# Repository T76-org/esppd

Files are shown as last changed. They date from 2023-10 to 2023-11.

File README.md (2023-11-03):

# ESPPD: a ESP32-S3 board with built-in USB-C PD controller

ESPPD

ESPPD is an ESP32-S3 breakout board that incorporates the ability to interface with a USB-C PD-compatible power supply to request a specific voltage. It features:

- **Hacker-friendly design**
  - Plug-and-play compatibility with Arduino and PlatformIO
  - Fits a standard breadboard, leaving a row of pins on each side for easy connectivity
  - Most ESP32-S3 pins available at the headers
  - 3.3V, VBUS (USB-PD input voltage), and GND pins on both sides
- **ESP32-S3-WROOM-1 module**
  - Dual 240 MHz dual-core Tensilica LX7 CPU
  - 2.4 GHz Wi-Fi (802.11n) and Bluetooth 5.0
  - 8MB SPI flash
  - 384 KB SRAM
- **USB-C PD 2.0 compatible controller**
  - Ability to request 5V, 9V, 12V, 15V, or 20V from a compatible supply
  - Ability to request a fixed voltage using hardwired jumpers, or dynamically via code
  - Ability to detect whether the requested voltage has actually been supplied (power-good signal)
- **Separate USB-C connectors for power and data**
  - Direct programming via USB; no UART required
  - USB 2.0 data connection
  - Support for USB host and client configuration
  - Serial I/O via USB supported out of the box
- **Indicators**
  - Power LED (red)
  - Software-controllable blue LED

## Hardware

The ESPPD incorporates a [CH224K](https://www.wch-ic.com/downloads/file/302.html) USB-PD controller that handles the negotiation with a PD-compatible power supply to request a specific voltage. The CH224K is configured to request 5V by default, but [can be configured](https://github.com/T76-org/esppd/wiki/Interfacing-with-USB-PD-devices) to request 5V, 9V, 12V, 15V, or 20V using either hardwired jumpers or dynamically via firmware. The CH224K also monitors the voltage supplied by the power supply and can report whether the requested voltage has actually been supplied, thus allowing your code to only operate under the correct conditions.

## ESP32-S3 compatibility

The board is compatible with the [ESP32-S3-WROOM-1](https://www.espressif.com/sites/default/files/documentation/esp32-s3-wroom-1_wroom-1u_datasheet_en.pdf) module from Espressif. The module features a dual-core 240 MHz Tensilica LX7 CPU, 4MB of SPI flash, up to 8MB of PSRAM, and 384 KB of SRAM. The module also features 2.4 GHz Wi-Fi (802.11n) and Bluetooth 5.0.

## Pinout

Pinout

For additional information on the features associated with each pin, you can consult [Espressif's ESP32-S3 datasheet](https://www.espressif.com/sites/default/files/documentation/esp32-s3_datasheet_en.pdf).

## Further reading

For more information on how to build and upload your code to the board, interact with a USB-PD power supply, and troubleshoot any problems, see the [wiki](https://github.com/T76-org/esppd/wiki).

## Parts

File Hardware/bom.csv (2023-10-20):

Designator | Footprint | Quantity | Value | LCSC Part #
C1, C5, C6 | 0402 | 3 | 1µ | C52923
C2, C3 | 1206 | 2 | 10µ | C13585
C4 | 0603 | 1 | 100n | C14663
C7 | 0603 | 1 | 22µ | C59461
C8 | 0402 | 1 | 100n | C1525
D1 | SMA_L4.3-W2.6-LS5.2-RD | 1 | SS34 | C8678
D2 | 0603 | 1 | POWER | C2286
D3 | 0603 | 1 | LED | C72041
J1 | PinHeader_1x22_P2.54mm_Vertical | 1 | Left
J2 | PinHeader_1x22_P2.54mm_Vertical | 1 | Right
JP1, JP2, JP3 | SolderJumper-3_P1.3mm_Open_RoundedPad1.0x1.5mm_NumberLabels | 3 | Jumper_3_Open
JP4 | SolderJumper-2_P1.3mm_Open_RoundedPad1.0x1.5mm | 1 | Jumper_2_Open
L1 | IND-SMD_L4.5-W4.0 | 1 | PSPCAQ43-100M | C436403
R1, R10, R11, R5, R6, R9 | 0402 | 6 | 10k | C25744
R12 | 0402 | 1 | 300R | C25102
R2, R7, R8 | 0402 | 3 | 1k | C11702
R3 | 0603 | 1 | 13k | C22797
R4 | 0603 | 1 | 3k9 | C23018
SW1, SW2 | SW-SMD_4P-L5.1-W5.1-P3.70-LS6.5-TL-2 | 2 | RESET | C318884
U2 | ESP32-S3-WROOM-1 | 1 | ESP32-S3-WROOM-1
U3 | SOT-23-6_L2.9-W1.7-P0.95-LS2.8-BL | 1 | LGS5145 | C5123971
U4 | ESSOP-10_L4.9-W3.9-P1.0-LS6.0-TL-EP | 1 | CH224K | C970725
USB1 | USB-C_SMD-TYPE-C-31-M-12 | 1 | PWR | C2927038
USB2 | USB-C_SMD-TYPE-C-31-M-12 | 1 | DATA | C2927038

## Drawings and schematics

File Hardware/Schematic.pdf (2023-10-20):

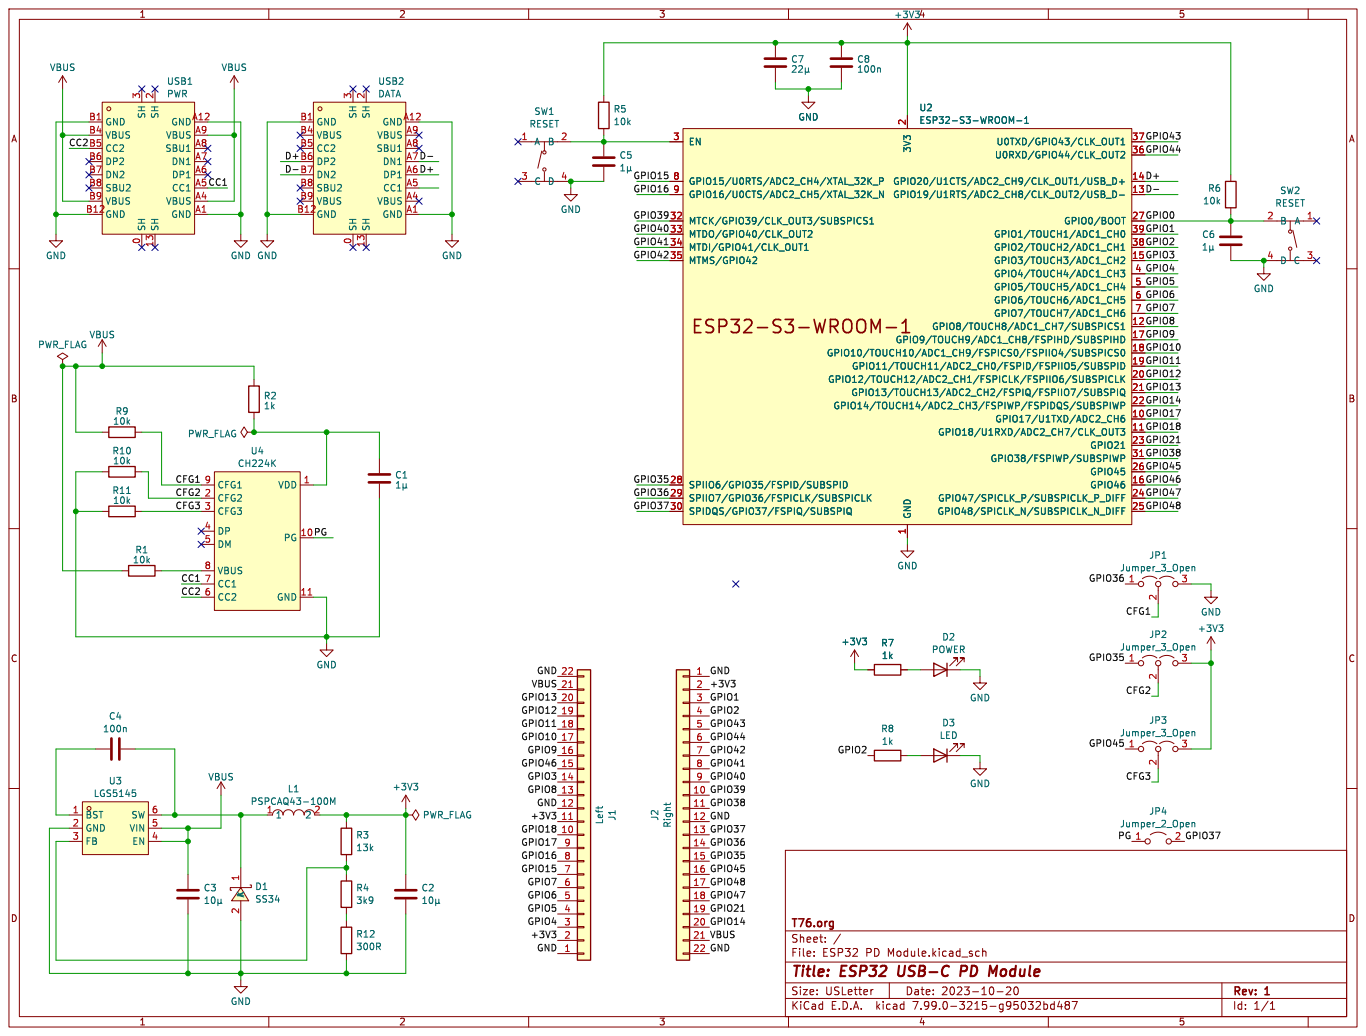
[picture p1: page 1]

3 GND A1 GNDA12 VBUS A4 CC1 A5 DP1 A6 DN1 A7 SBU1 A8 VBUS A9 GND B1 GND B12 VBUS B4 CC2 B5 DP2 B6 DN2 B7 SBU2 B8 VBUS B9 USB1 PWR GND

3 GND A1 GNDA12 VBUS A4 CC1 A5 DP1 A6 DN1 A7 SBU1 A8 VBUS A9 GND B1 GND B12 VBUS B4 CC2 B5 DP2 B6 DN2 B7 SBU2 B8 VBUS B9 USB2 DATA R5

2 GPIO12/TOUCH12/ADC2_CH1/FSPICLK/FSPIIO6/SUBSPICLK 20 GPIO13/TOUCH13/ADC2_CH2/FSPIQ/FSPIIO7/SUBSPIQ 21 GPIO14/TOUCH14/ADC2_CH3/FSPIWP/FSPIDQS/SUBSPIWP 22 GPIO21 23 GPIO47/SPICLK_P/SUBSPICLK_P_DIFF 24 GPIO48/SPICLK_N/SUBSPICLK_N_DIFF 25 GPIO45 26 GPIO0/BOOT 27 SPIIO6/GPIO35/FSPID/SUBSPID 28 SPIIO7/GPIO36/FSPICLK/SUBSPICLK 29 EN 3 SPIDQS/GPIO37/FSPIQ/SUBSPIQ 30 GPIO38/FSPIWP/SUBSPIWP 31 MTCK/GPIO39/CLK_OUT3/SUBSPICS1 32 MTDO/GPIO40/CLK_OUT2 33 MTDI/GPIO41/CLK_OUT1 34 MTMS/GPIO42 35 U0RXD/GPIO44/CLK_OUT2 36 U0TXD/GPIO43/CLK_OUT1 37 GPIO2/TOUCH2/ADC1_CH1 38 GPIO1/TOUCH1/ADC1_CH0 39 GPIO4/TOUCH4/ADC1_CH3 4 GPIO5/TOUCH5/ADC1_CH4 5 GPIO6/TOUCH6/ADC1_CH5 6 GPIO7/TOUCH7/ADC1_CH6 7 GPIO15/U0RTS/ADC2_CH4/XTAL_32K_P 8 GPIO16/U0CTS/ADC2_CH5/XTAL_32K_N 9 U2ESP32-S3-WROOM-1 SH

2 GPIO12/TOUCH12/ADC2_CH1/FSPICLK/FSPIIO6/SUBSPICLK 20 GPIO13/TOUCH13/ADC2_CH2/FSPIQ/FSPIIO7/SUBSPIQ 21 GPIO14/TOUCH14/ADC2_CH3/FSPIWP/FSPIDQS/SUBSPIWP 22 GPIO21 23 GPIO47/SPICLK_P/SUBSPICLK_P_DIFF 24 GPIO48/SPICLK_N/SUBSPICLK_N_DIFF 25 GPIO45 26 GPIO0/BOOT 27 SPIIO6/GPIO35/FSPID/SUBSPID 28 SPIIO7/GPIO36/FSPICLK/SUBSPICLK 29 EN 3 SPIDQS/GPIO37/FSPIQ/SUBSPIQ 30 GPIO38/FSPIWP/SUBSPIWP 31 MTCK/GPIO39/CLK_OUT3/SUBSPICS1 32 MTDO/GPIO40/CLK_OUT2 33 MTDI/GPIO41/CLK_OUT1 34 MTMS/GPIO42 35 U0RXD/GPIO44/CLK_OUT2 36 U0TXD/GPIO43/CLK_OUT1 37 GPIO2/TOUCH2/ADC1_CH1 38 GPIO1/TOUCH1/ADC1_CH0 39 GPIO4/TOUCH4/ADC1_CH3 4 GPIO5/TOUCH5/ADC1_CH4 5 GPIO6/TOUCH6/ADC1_CH5 6 GPIO7/TOUCH7/ADC1_CH6 7 GPIO15/U0RTS/ADC2_CH4/XTAL_32K_P 8 GPIO16/U0CTS/ADC2_CH5/XTAL_32K_N 9 R7

1 GPIO17/U1TXD/ADC2_CH6 10 GPIO18/U1RXD/ADC2_CH7/CLK_OUT3 11 GPIO8/TOUCH8/ADC1_CH7/SUBSPICS1 12 GPIO19/U1RTS/ADC2_CH8/CLK_OUT2/USB_D- 13 GPIO20/U1CTS/ADC2_CH9/CLK_OUT1/USB_D+ 14 GPIO3/TOUCH3/ADC1_CH2 15 GPIO46 16 GPIO9/TOUCH9/ADC1_CH8/FSPIHD/SUBSPIHD 17 GPIO10/TOUCH10/ADC1_CH9/FSPICS0/FSPIIO4/SUBSPICS0 18 GPIO11/TOUCH11/ADC2_CH0/FSPID/FSPIIO5/SUBSPID 19 3V3

Id: 1/1 Title: ESP32 USB-C PD Module

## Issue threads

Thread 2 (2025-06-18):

Testing with Apple charger

sumit809, 2025-06-18:
Hi,

Can you please confirm if this setup works with Apple USB Type-C chargers?
Also, is there any specific reason for not using the same Power USB-C connector for Data as well?

Regards,
Sumit

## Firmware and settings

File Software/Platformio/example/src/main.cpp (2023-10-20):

#include <Arduino.h>
#include <ch224k.hpp>

CH224KController CH224K;

void setup() {
  // Initialize the CH224K chip. This requests 5V by default.
  CH224K.begin();

  Serial.begin(115200);
}

CH224KVoltage voltages[] = {
  V5,
  V9,
  V12,
  V15,
  V20
};

String voltageNames[] = {
  "5V",
  "9V",
  "12V",
  "15V",
  "20V"
};

void loop() {
  // Cycle through all the voltages, waiting 3 seconds
  // between each voltage and the next. For each step,
  // write out the current request voltage, and wait until
  // the power good signal is high.

  for (int i = 0; i < 5; i++) {
    CH224K.setVoltageSetPoint(voltages[i]);
    Serial.print("Requested ");
    Serial.print(voltageNames[i]);
    Serial.print("...");

    delay(300);
    Serial.println(CH224K.powerGood() ? "power good!" : "power bad!");

    delay(3000);
  }
}
